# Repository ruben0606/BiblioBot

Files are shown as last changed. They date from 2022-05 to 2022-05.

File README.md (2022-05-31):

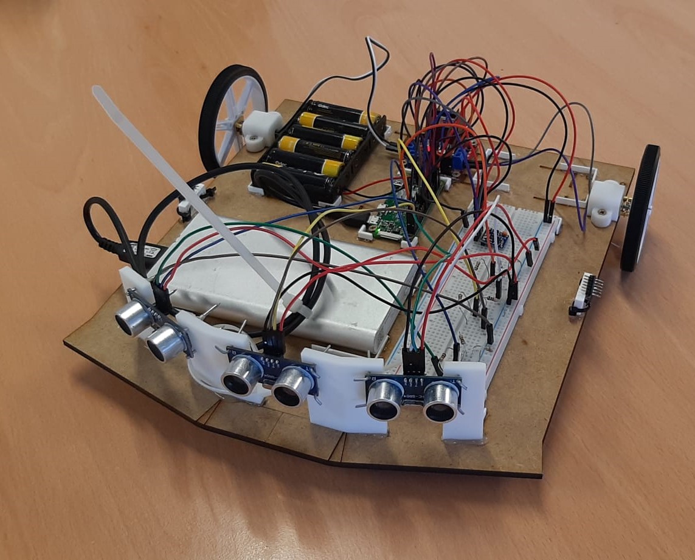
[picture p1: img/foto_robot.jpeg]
header pic


# BiblioBot
Project de l'assignatura Robòtica, llenguatge i planificació.

# Table of Contents
   * [What is this?](#what-is-this)
   * [Requirements](#requirements)
   * [Hardware](#hardware)
     * [Components](#components)
     * [Circuit](#circuit)  
     * [Resultat final](#resultat-final)
   * [Software](#software)
   * [3D printing](#3d-printing)
   * [How to use](#how-to-use)
   * [License](#license)
   * [Contribution](#contribution)
   * [Citing](#citing)
   * [Sponsors](#sponsors)
   * [Authors](#authors)
   * [Bibliography](#bibliography)

# What is this?
Projecte creat per un grup de 3 estudiants de la UAB que consisteix en la creació d'un robot dissenyat per ajudar als bibliotecaris i bibliotecàries a fer baixar el to de veu a la gent.

Features:
1. Autonomous movement module
2. Obstacle detection module
3. Audio advise module
4. Sound triangulation module
5. Person detection module

# Requirements
Per executar el codi d'aquest project:
- [Python 3.10.x](https://www.python.org/)
- [playsound](https://pypi.org/project/playsound/)
- [smbus](https://pypi.org/project/smbus-cffi/)
- [pygame](https://pypi.org/project/pygame/)
- [math](https://docs.python.org/es/3/library/math.html)
- [time](https://pypi.org/project/python-time/)

# Hardware

## Components

Per realitzar el Bibliobot s'han utilitzat una sèrie de components que podeu trobar en la seva totatilat fent click al següent enllaç:

[Enllaç components](https://github.com/ruben0606/BiblioBot/blob/main/components/components.txt)

A continucació mostrem els principals components acompanyats d'una petita explicació del seu ús en el nostre projecte.

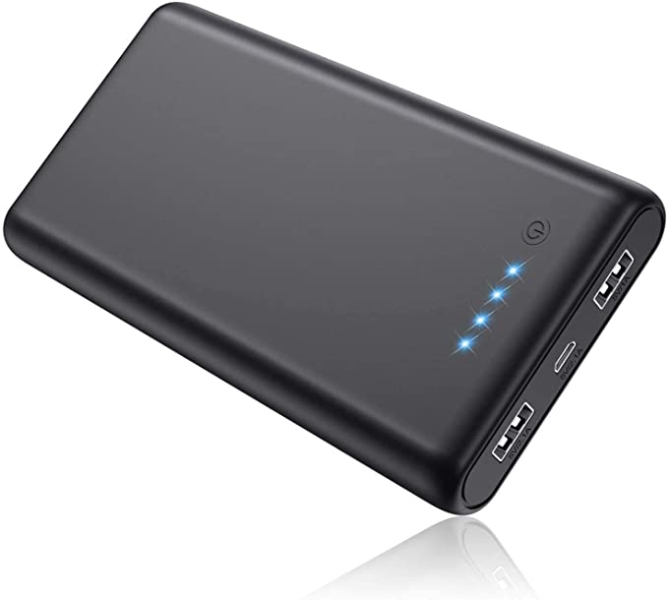
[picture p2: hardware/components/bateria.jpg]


*Batería que alimentarà els motors*

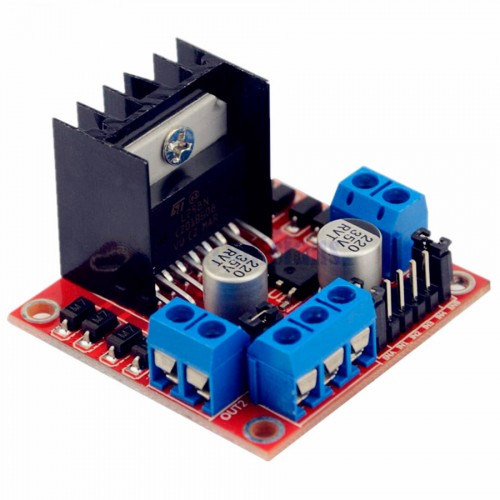
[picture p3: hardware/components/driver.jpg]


*Driver L298N que serviràn per manipulars els motors desde la Raspberry*

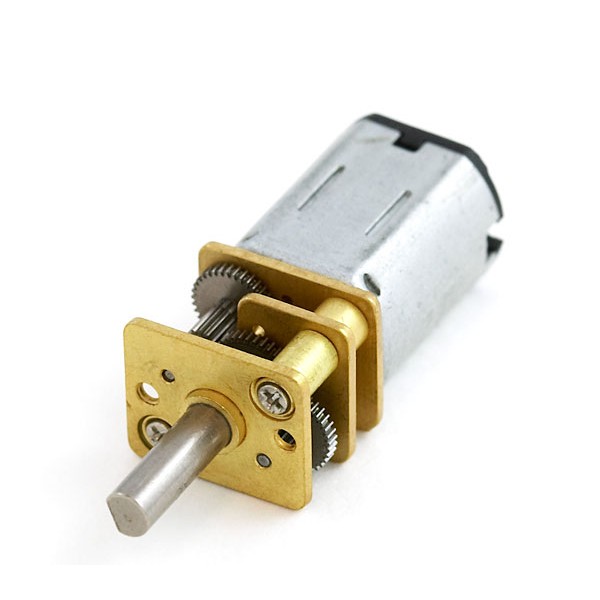
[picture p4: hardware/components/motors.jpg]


*Motors s'encarregaràn de transmetre moviment a les rodes*

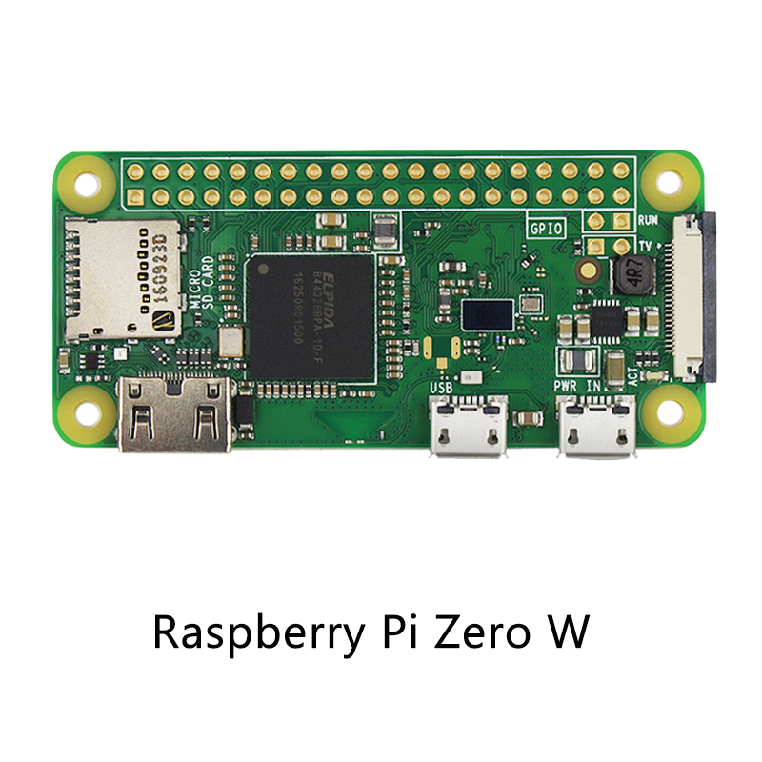
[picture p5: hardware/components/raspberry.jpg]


*Raspberry Pi Zero W, s'encarrega de controlar la resta de components*

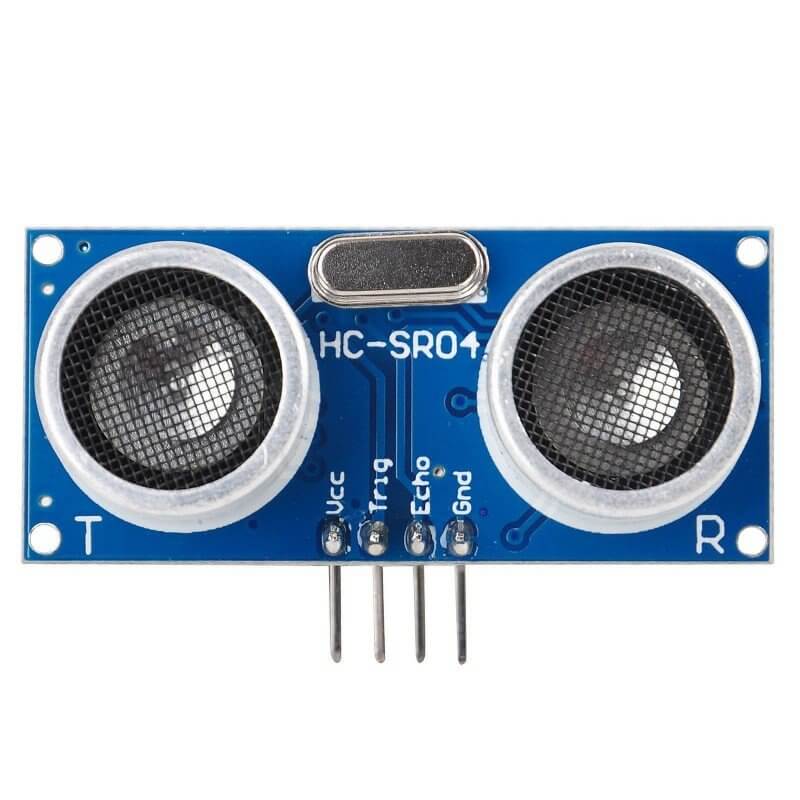
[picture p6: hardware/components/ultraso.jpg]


*Sensors d'ultrasò HC-SR04 detecta obstacles a una certa distància del robot*

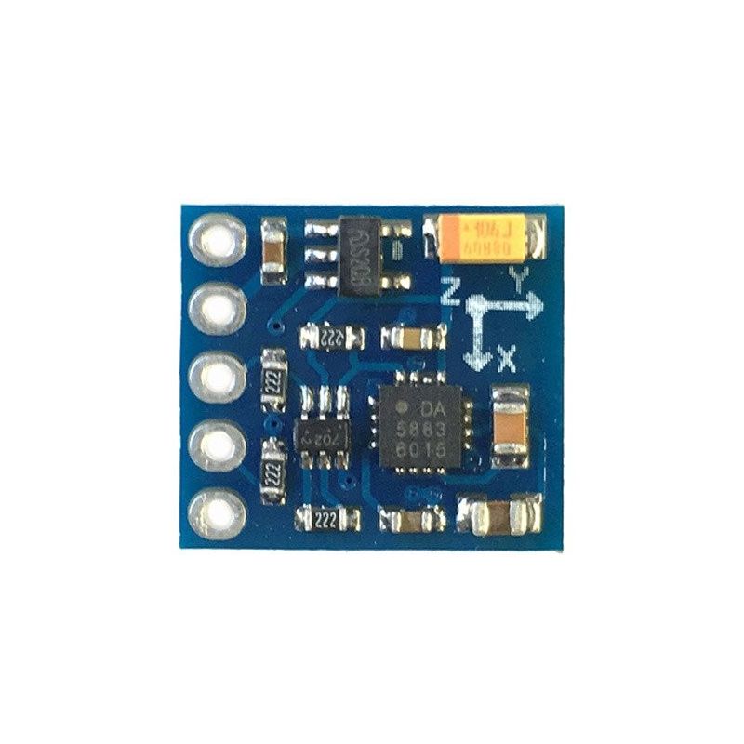
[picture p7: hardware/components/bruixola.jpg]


*Brúixola que indicarà la direcció del nord per poder orientar al Bibliobot.*

## Circuit

A continuació es pot observar una simulació del circuit necessàri realitzat amb Fritzering. Per obtenir tots els components s'haurà de descarregar una sèrie de llibreries que deixem a l'enllaç de continuació:

[Llibreries fritzering](https://github.com/adafruit/Fritzing-Library)

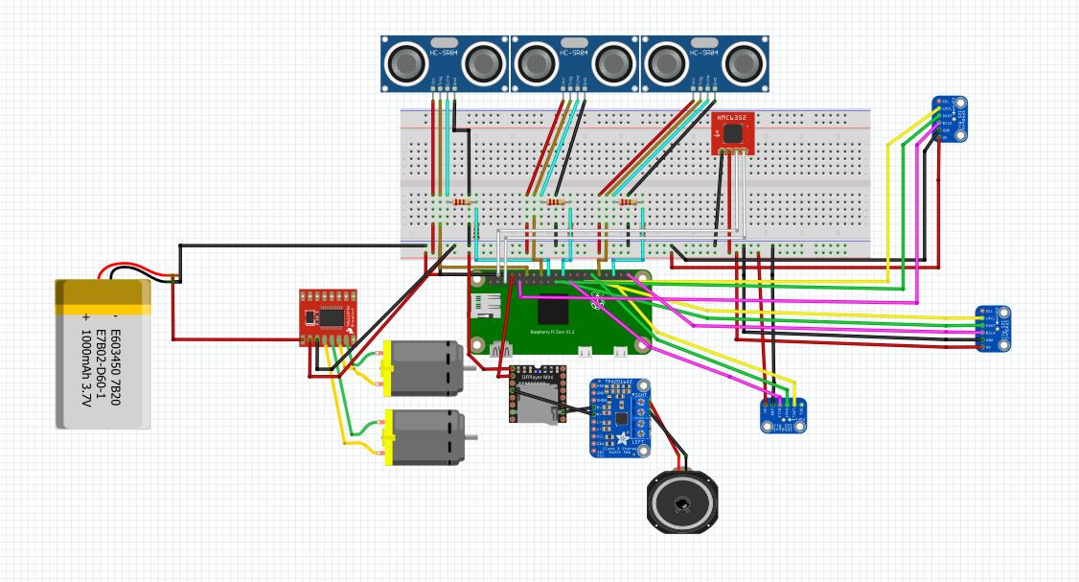
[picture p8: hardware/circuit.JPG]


Si voleu saber quins pins hem utilitzat específicament per realitzar la versió final del bibliobot els podeu consultar al següent enllaç:

[Pinout Bibliobot](/pinout_bibliobot.txt)

## Resultat final

A continuació mostrem una sèrie d'imatges de la versió final del robot.



*Imatge de la versió final del Bibliobot*

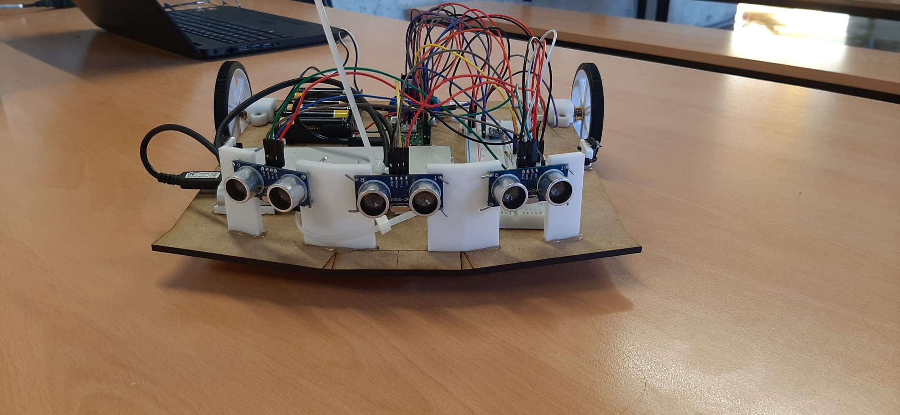
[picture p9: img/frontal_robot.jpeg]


*Vista frontal del Bibliobot*

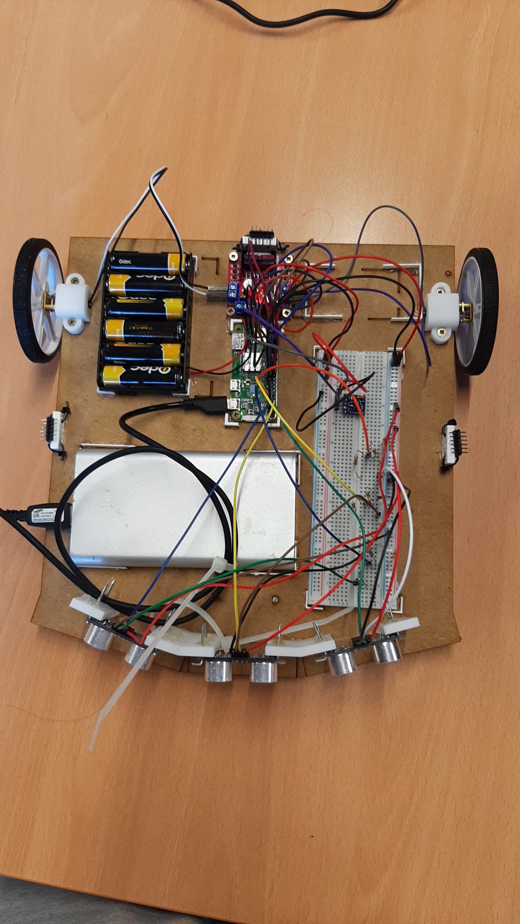
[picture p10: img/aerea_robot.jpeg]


*Vista aèrea del Bibliobot*

# Software

A nivell de software el projecte conté tres grans mòduls:

-**Mòdul de Moviment:**
S'encarrega del moviment del robot, que es podrà moure en les tres direccions programades, cap endavant, esquerra i dreta.
Simplement conté la programació perquè el robot pugui avançar cap a la direcció que se l'indiqui en tot moment segons la situació actual que tingui.
Aquesta situació actual dependrà de si el mòdul de detecció d'obstacles li informa que hem topat amb un obstacle.

-**Mòdul de detecció d'obstacles:**
S'encarrega de detectar els obstacles que el Bibliobot va trobant al llarg del seu recorregut. Aquest mòdul informarà al mòdul de moviment quan detecti un obstacle i li dirà per quina direcció l'ha detectat. Això ho sabrà segons quin sensor d'ultrasò HC-sr04 hagi detectat l'obstacle i li passarà a l'altre mòdul una senyal perquè pugui actuar.
Els sensors estàn separats amb una angle de 15 graus entre si per poder localitzar correctament si un objecte es troba davant, a l'esquerra o a la dreta i que no pugui haver confusió.

-**Mòdul de reproducció de so:**
S'encarrega de reproduïr una frase a través d'un altaveu un cop hagi arribat al destí per fer saber a la persona indicada que ha de baixar el to de veu. Depèn del mòdul de moviment per saber quan arribem al destí, que serà quan ha d'executar l'ordre.
Un cop intervé aquest mòdul Bibliobot ha acabat la seva tasca i espera a tornar a haver d'intervenir.

A continuació es mostra una imatge amb els mòduls software i les dependències entre ells:

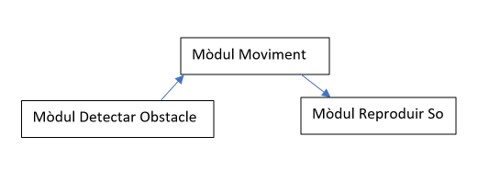
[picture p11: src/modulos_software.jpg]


**PROGRAMA PRINCIPAL**
El programa principal (main) s'encarrega d'inicialitzar els pins i variables i cridar a les funcions corresponents als mòduls de software per obtenir la solució. 
En aquest cas la crida a alguns mòduls retornarà l'entrada a uns altres (com la detecció d'obstacles i el moviment) i gestionarà a quina posició ha d'anar Bibliobot i quan ha arribat a la mateixa.
El programa consta bàsicament d'un bucle continu en el qual el robot farà el següent:

1. Prenem la direcció del robot amb la brúixola.
2. Mirem si hi han obstacles i en que posició es troben.
3. Esquivem els objectes segons on es trobin i la direcció del robot.

Del punt 3 es passarà a l'1 si no arribem a destí. En cas d'arribar el robot manarà a callar a la persona objectiu.

# 3D printing

Per a la realització del Bibliobot s'han hagut d'imprimir diverses peces 3d. Aquestes peces 3d s'han imprès a l'Open Lab de la Universitat Autònoma de Barcelona (UAB).

S'ha utilitzat el programa Fusion 360 per realitzar totes les peces.

La primera peça realitada és la peça principal del projecte ja que serà la base del nostre robot. La peça consta de la base i al seu interior hem dissenyat unes sub-peces per poder colocar els components corresponents sense que caiguin de la base amb el moviment del robot.
Aquestes subpeces són pestanyes que envolten les peces per així fixar-les a la base i al disseny es poden observar les peces que serveixen per anclar uns altres components amb cargols.

La base es va decidir fer amb la talladora làser en fusta ja que era molt més ràpid. 

A continuació mostrem el resultat:
  
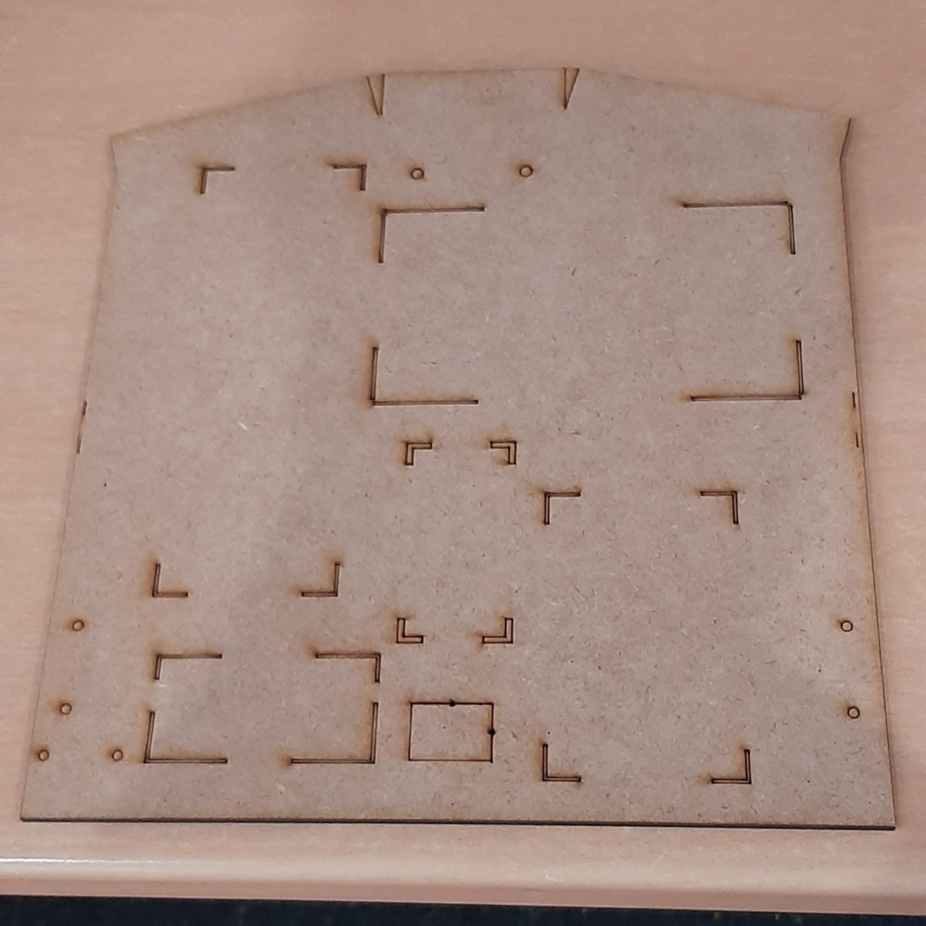
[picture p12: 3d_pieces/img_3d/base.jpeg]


*Base de fusta tallada a làser*

També es van realitzar els suports per mantenir fixos els sensors d'ultrasò HC-sr04, els motors i els micròfons. En el cas del sensors es van situar amb una diferència de 15 graus entre ells per poder detectar millor els obstàcles.

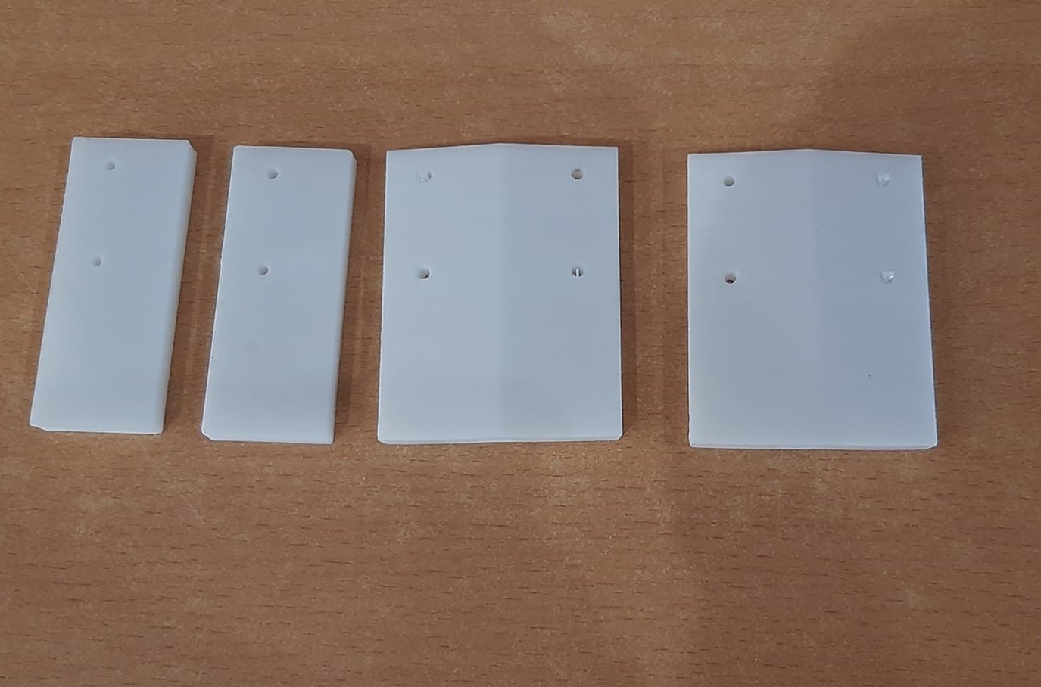
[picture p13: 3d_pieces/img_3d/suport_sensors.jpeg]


*Peces per aguantar els sensors HC-sr04 i mantenirlos a un angle de 15 graus entre ells.*

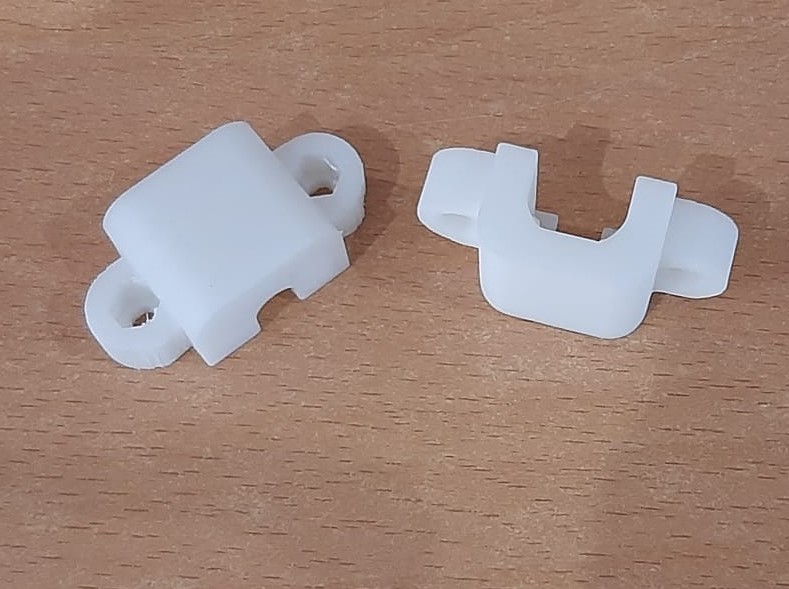
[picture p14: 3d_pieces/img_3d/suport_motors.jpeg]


*Suports de motors obtinguts d'internet*

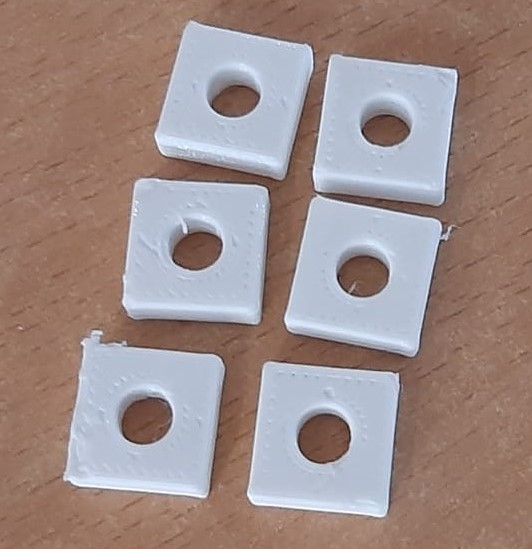
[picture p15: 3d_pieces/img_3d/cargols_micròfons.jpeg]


*Peces per aguantar els micròfons de forma que quedin triangulats*

Per últim, com hem esmentat abans, s'han realitzat múltiples pestanyes per fixar els components més pesats i amb major risc de voltejar o caure.

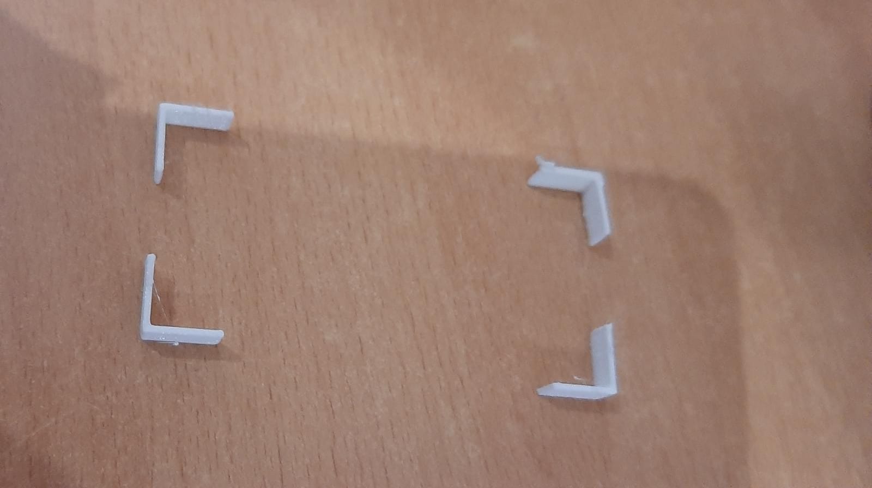
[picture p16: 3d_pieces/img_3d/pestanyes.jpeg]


*Exemple de pestanyes per fixar els components*

# How to use
1. Connectar-se el dispositiu raspberry pi zero w mitjançant ssh.

2. Clonar aquest repositori des de terminal.
> git clone https://github.com/ruben0606/BiblioBot.git

3. Instal·lar les llibreries necessaries.

Utilitzar l'eina pip:

> pip install -r requirements/requirements.txt

4. Executar el python script que es troba en la carpeta src.
> python src/Bibliobot.py

# License
MIT

# Use-case
Encara no tenim cap cas d'ús d'altres usuaris.

# Contribution
Qualsevol tipus de contribució serà benvinguda!

# Citing
Si utilitzeu el codi d'aquest projecte per al vostre propi projecte, us animem a citar els nostres treballs.

# Supporting this project
Agraïm que esteu interessats en aquest project, però no acceptem cap tipus donació.

# Sponsors

### [Open Labs UAB](https://www.uab.cat/open-labs/)

Impressió de peces 3D amb ells de forma gratuïta per projecte de la UAB.

### [Universitat Atònomma de Barcelona (UAB)](https://www.uab.cat/)

Facilitació dels components necessàris per la realització del projecte.

# Authors
- [Col·laboradors d'aquest project](https://github.com/ruben0606/BiblioBot/graphs/contributors)

# Bibliography
1. https://rlpengineeringschooluab2017.wordpress.com/2017/05/31/soundhound/
2. https://rlpengineeringschooluab2017.wordpress.com/2017/05/30/the-follower/
3. https://www.electronicshub.org/raspberry-pi-l298n-interface-tutorial-control-dc-motor-l298n-raspberry-pi/
4. https://cdn.sparkfun.com/assets/learn_tutorials/6/7/6/PiZero_1.pdf
5. https://blog.330ohms.com/2020/06/17/como-conectar-un-sensor-ultrasonico-a-raspberry-pi/
6. https://github.com/ShrimpingIt/micropython-dfplayer
7. https://www.reddit.com/r/raspberrypipico/comments/q19v0n/dfplayer_with_pico/
8. https://www.electroallweb.com/index.php/2020/07/22/modulo-dfplayer-mini-reproductor-mp3-tutorial-completo/
9. https://pimylifeup.com/raspberry-pi-omxplayer/
10. https://www.hackster.io/miguel-a-lopez-monzon/triangulation-of-sound-87d3b8
11. https://forums.raspberrypi.com/viewtopic.php?t=165996
12. https://forum.arduino.cc/t/sound-triangulation-with-3-microphones/122940
13. https://www.youtube.com/watch?v=3LBiyBTnt7g&ab_channel=Maker%27sDigest
14. http://dimcad3d.com/2016/04/27/fusion-360-tutoriales-en-espanol/
15. https://descubrearduino.com/audio-bluetooth-raspberry-pi/
16. https://www.electronicwings.com/raspberry-pi/mpu6050-accelerometergyroscope-interfacing-with-raspberry-pi
17. https://forums.raspberrypi.com/viewtopic.php?t=184556
18. https://electropeak.com/learn/interfacing-gy-271-hmc5883l-compass-magnetometr-with-arduino/
19. https://arduinoque.com/robots/sensor-de-movimiento-raspberry-pi/
20. https://forums.raspberrypi.com/viewtopic.php?t=166156
21. https://components101.com/modules/l293n-motor-driver-module

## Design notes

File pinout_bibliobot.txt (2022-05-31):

BOARD PINS

HC-RS04
----------
TRIGL = 40
TRIGC = 38
TRIGR = 36

ECHOL = 37
ECHOC = 35
ECHOR = 33

GY-271
----------
SCL = 3
SDA = 5

L298N
----------
IN1 = 16
IN2 = 18
IN3 = 19
IN4 = 15
ENA = 22
ENB = 23

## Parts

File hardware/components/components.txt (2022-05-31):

-Raspberry pi zero w
-Sensors dl'ultrasò HC-SR04 (x3)
-Protoboard
-Drivers L298N
-Altaveu bluetooth
-Motor Micrometal LP
-Batería Lipo
-Rodes(x2)
-Roda boja
-Portapiles (6 piles)
-Micròfons I2S SPH0645

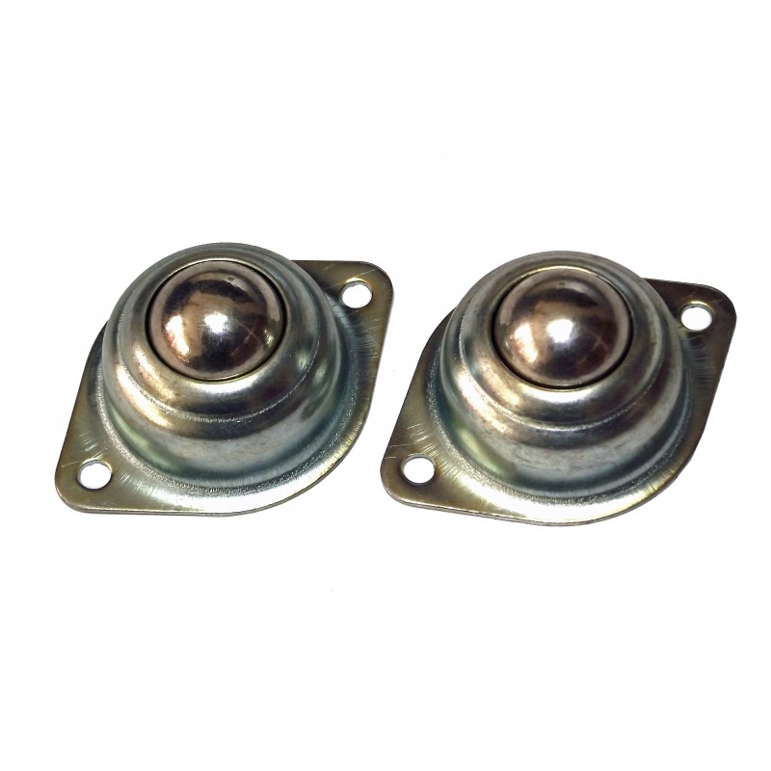
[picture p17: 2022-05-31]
hardware/components/roda_boja.jpg

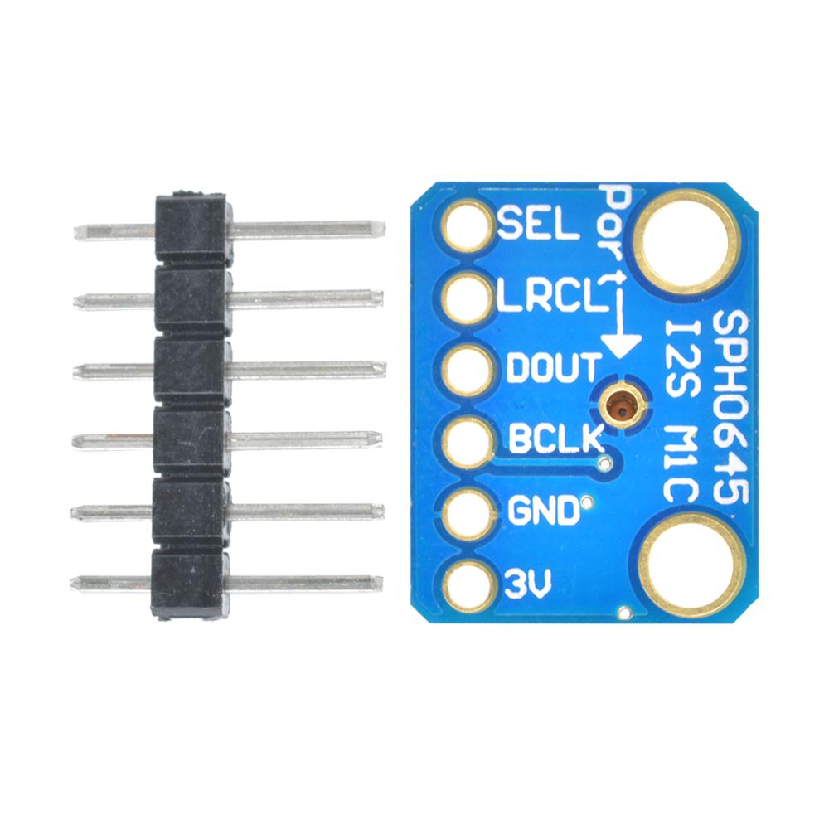
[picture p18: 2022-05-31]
hardware/components/microfons.jpeg

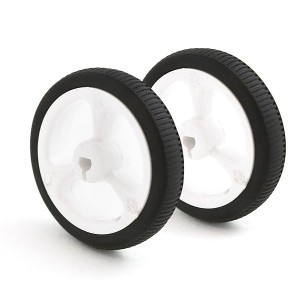
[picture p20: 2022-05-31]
hardware/components/rodes.jpg

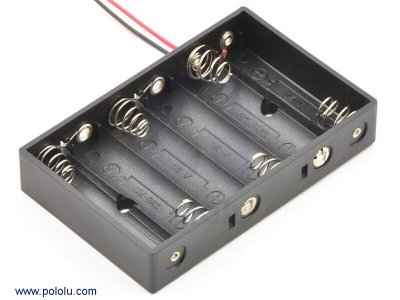
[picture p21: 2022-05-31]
hardware/components/portapiles.jpg

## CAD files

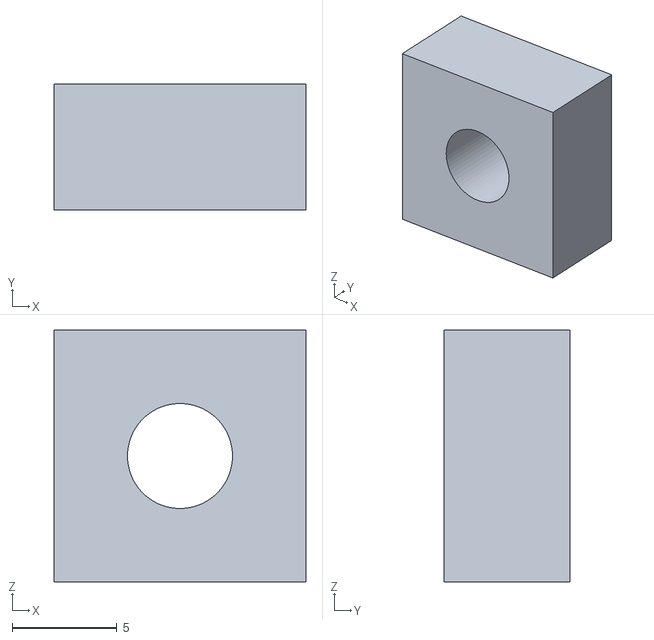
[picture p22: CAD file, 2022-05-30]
3d_pieces/soporte_micros.stl
12.0 x 6.00 x 12.0

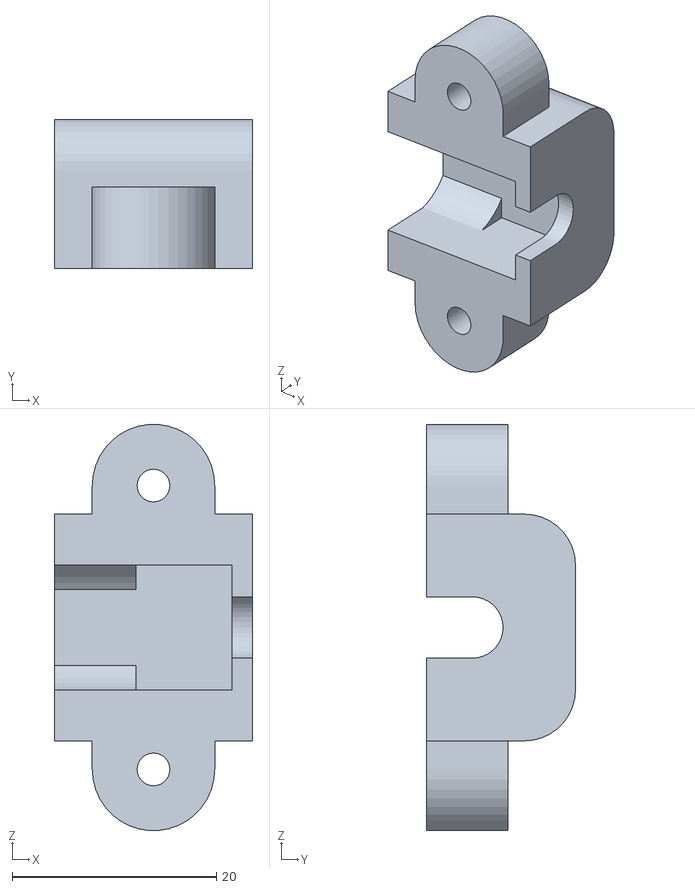
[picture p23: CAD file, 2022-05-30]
3d_pieces/soporte_motores.STL
19.4 x 14.6 x 39.8

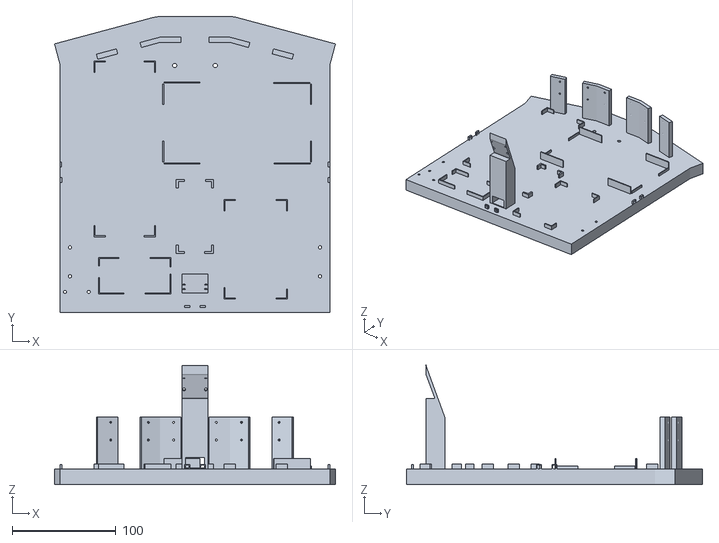
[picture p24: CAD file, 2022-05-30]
3d_pieces/base_robot.stl
270.3 x 285.0 x 114.9

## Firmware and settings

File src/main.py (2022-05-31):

import RPi.GPIO as GPIO
import time
import smbus  # comunicación I2C
import math
import pygame


# direcciones requeridas
# ---------------config
Registro_A = 0x0B
Registro_B = 0x09
RegStatus = 0x06
RegCtrl = 0x09
# ---------------direcciones de la conexión
bus = smbus.SMBus(1)
deviceAdress = 0x0d
# ---------------datos
eje_X_Mag = 0x00
eje_Y_Mag = 0x02
eje_Z_Mag = 0x04
declination = -0.00669
pi = 3.14159265359


distance_thfreshold = 15

#PINOUT
#HC-RS04
#----------
TRIGL = 40
TRIGC = 38
TRIGR = 36

ECHOL = 37
ECHOC = 35
ECHOR = 33

#GY-271
#----------
SCL = 3
SDA = 5

#L298N
#----------
IN1 = 16
IN2 = 18
IN3 = 19
IN4 = 15
ENA = 22
ENB = 23

TIME = 20

GPIO.setmode(GPIO.BOARD)

GPIO.setup(TRIGL,GPIO.OUT)
GPIO.setup(TRIGC,GPIO.OUT)
GPIO.setup(TRIGR,GPIO.OUT)
GPIO.setup(IN1,GPIO.OUT)
GPIO.setup(IN2,GPIO.OUT)
GPIO.setup(IN3,GPIO.OUT)
GPIO.setup(IN4,GPIO.OUT)
GPIO.setup(ENA,GPIO.OUT)
GPIO.setup(ENB,GPIO.OUT)

GPIO.setup(ECHOL,GPIO.IN)
GPIO.setup(ECHOC,GPIO.IN)
GPIO.setup(ECHOR,GPIO.IN)

def ultrasound(TRIG, ECHO):
    # print("Distance in cm: ")

    try:
        GPIO.output(TRIG, False)
        print("Waiting to settle sensor")
        time.sleep(0.5)
        GPIO.output(TRIG, True)
        time.sleep(0.00001)
        GPIO.output(TRIG, False)
        while True:
            pulse_start = time.time()
            if GPIO.input(ECHO) == GPIO.HIGH:
                break
        while True:
            pulse_end = time.time()
            if GPIO.input(ECHO) == GPIO.LOW:
                break
        pulse_duration = pulse_end - pulse_start
        distance = pulse_duration * 17150
        distance = round(distance, 2)
        print("Distance: %f cm", distance)
        return distance

    except KeyboardInterrupt:
        print("Interrupted")
        GPIO.cleanup()


def movement(dir_obj, dir_robot, obstacles): #obstacles = [right, center, left] (bools) if obstacle or not
    if dir_obj == dir_robot:
        if obstacles[1] == True:
            #go forward
            GPIO.output(IN1, GPIO.LOW)
            GPIO.output(IN2, GPIO.HIGH)
            GPIO.output(IN3, GPIO.LOW)
            GPIO.output(IN4, GPIO.HIGH)
        elif obstacles[2] == True:
            #turn right
            GPIO.output(IN1, GPIO.HIGH)
            GPIO.output(IN2, GPIO.LOW)
            GPIO.output(IN3, GPIO.LOW)
            GPIO.output(IN4, GPIO.HIGH)
        elif obstacles[0] == True:
            #turn left
            GPIO.output(IN1, GPIO.LOW)
            GPIO.output(IN2, GPIO.HIGH)
            GPIO.output(IN3, GPIO.HIGH)
            GPIO.output(IN4, GPIO.LOW)
        else:
            #detenerse
            GPIO.output(IN1, GPIO.LOW)
            GPIO.output(IN2, GPIO.LOW)
            GPIO.output(IN3, GPIO.LOW)
            GPIO.output(IN4, GPIO.LOW)
    else:
        #alinear direccion
        if dir_robot - dir_obj < 0:
            #turn right
            GPIO.output(IN1, GPIO.HIGH)
            GPIO.output(IN2, GPIO.LOW)
            GPIO.output(IN3, GPIO.LOW)
            GPIO.output(IN4, GPIO.HIGH)
        elif dir_robot - dir_obj > 0:
            # turn left
            GPIO.output(IN1, GPIO.LOW)
            GPIO.output(IN2, GPIO.HIGH)
            GPIO.output(IN3, GPIO.HIGH)
            GPIO.output(IN4, GPIO.LOW)

def MagnetometerInit():
    # configurar registro A
    bus.write_byte_data(deviceAdress, Registro_A, 0x01)
    # configurar registro B
    bus.write_byte_data(deviceAdress, Registro_B, 0x1D)
    # configurar registro para seleccionar el modo
    # bus.write_byte_data(deviceAdress, ModoRegistro, 0)

def read_raw_data(addr):
    # leer doble byte (16 bits)
    low = bus.read_byte_data(deviceAdress, addr)
    high = bus.read_byte_data(deviceAdress, addr + 1)
    # concatenar los bytes
    valor = ((high << 8) | low)
    # obtener el signo
    if (valor > 32768):
        valor = valor - 65536
    return valor

def accelerometro():
    print('leyendo magnetometro...')
    #while True:
    bandera = bus.read_byte_data(deviceAdress, RegStatus)
    a = "{0:b}".format(bandera)
    if a[len(a) - 1] == 0:
        bandera = bus.read_byte_data(deviceAdress, RegStatus)
    x = read_raw_data(eje_X_Mag)
    y = read_raw_data(eje_Y_Mag)
    z = read_raw_data(eje_Z_Mag)
    heading = math.atan2(y, x) + declination
    # compensar superiores a 360
    if (heading > 2 * pi):
        heading = heading - 2 * pi
    # revisar el signo
    if (heading < 0):
        heading = heading + 2 * pi
        # convertir a grados
    heading_angle = int(heading * (180 / pi))
    print("angulo = %d°" % heading_angle)
    #sleep(0.5)
    return heading_angle

def call():
    pygame.mixer.init()
    pygame.mixer.music.load("king.mp3")
    pygame.mixer.music.play()
    while pygame.mixer.music.get_busy() == True:
        continue

def main():
    start = time.time()
    MagnetometerInit()
    dir_objetivo = 100
    while True:
        dir_robot = accelerometro()
        distances = []
        dist_1 = ultrasound(TRIGR, ECHOR)
        distances.append(dist_1)
        dist_2 = ultrasound(TRIGC, ECHOC)
        distances.append(dist_2)
        dist_3 = ultrasound(TRIGL, ECHOL)
        distances.append(dist_3)
        obstacles = []
        for dist in distances:
            if dist < distance_thfreshold:  # si la distancia en un detector es menor a la minima
                obstacles.append(True)
            else:
                obstacles.append(False)
        movement(dir_objetivo,dir_robot,obstacles)
        end = time.time()
        if end - start > TIME:
            break
    call()

if __name__ == '__main__':
    main()

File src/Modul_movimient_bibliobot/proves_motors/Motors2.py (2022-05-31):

# -*- coding: utf-8 -*-
"""
Created on Wed May 25 09:44:07 2022

@author: rubeg
"""
#PROVA 2 MOTORS

import RPi.GPIO as GPIO
from time import sleep
 
GPIO.setmode(GPIO.BOARD)
Motor1A = 16
Motor1B = 18
Motor1E = 22
Motor2A = 23
Motor2B = 21
Motor2E = 19
GPIO.setup(Motor1A,GPIO.OUT)
GPIO.setup(Motor1B,GPIO.OUT)
GPIO.setup(Motor1E,GPIO.OUT)

GPIO.setup(Motor2A,GPIO.OUT)
GPIO.setup(Motor2B,GPIO.OUT)
GPIO.setup(Motor2E,GPIO.OUT)

print("Going forwards")

GPIO.output(Motor1A,GPIO.HIGH)
GPIO.output(Motor1B,GPIO.LOW)
GPIO.output(Motor1E,GPIO.HIGH)

GPIO.output(Motor2A,GPIO.HIGH)
GPIO.output(Motor2B,GPIO.LOW)
GPIO.output(Motor2E,GPIO.HIGH)
sleep(2)

print("Going backwards")
GPIO.output(Motor1A,GPIO.LOW)
GPIO.output(Motor1B,GPIO.HIGH)
GPIO.output(Motor1E,GPIO.HIGH)
 
GPIO.output(Motor2A,GPIO.LOW)
GPIO.output(Motor2B,GPIO.HIGH)
GPIO.output(Motor2E,GPIO.HIGH)
sleep(2)

print("Now stop")

GPIO.output(Motor1E,GPIO.LOW)
GPIO.output(Motor2E,GPIO.LOW)
 
GPIO.cleanup()

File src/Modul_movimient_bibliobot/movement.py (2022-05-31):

# -*- coding: utf-8 -*-
"""
Created on Tue May 31 23:35:06 2022

@author: rubeg
"""

import curses
import RPi.GPIO as GPIO

GPIO.setmode(GPIO.BCM)
GPIO.setup(20, GPIO.OUT)
GPIO.setup(26, GPIO.OUT)
GPIO.setup(19, GPIO.OUT)
GPIO.setup(16, GPIO.OUT)

def main(letra):
    while True:
        curses.halfdelay(1)
        key = letra.getch()
        #print key
        if key == 113:
            break
        elif key == 119:
            print "adelante"
            GPIO.output(20, GPIO.LOW)
            GPIO.output(26, GPIO.HIGH)
            GPIO.output(19, GPIO.LOW)
            GPIO.output(16, GPIO.HIGH)
        elif key == 97:
            print "izquierda"
            GPIO.output(20, GPIO.LOW)
            GPIO.output(26, GPIO.HIGH)
            GPIO.output(19, GPIO.HIGH)
            GPIO.output(16, GPIO.LOW)
        elif key == 115:
            print "atras"
            GPIO.output(20, GPIO.HIGH)
            GPIO.output(26, GPIO.LOW)
            GPIO.output(19, GPIO.HIGH)
            GPIO.output(16, GPIO.LOW)
        elif key == 100:
            print "derecha"
            GPIO.output(20, GPIO.HIGH)
            GPIO.output(26, GPIO.LOW)
            GPIO.output(19, GPIO.LOW)
            GPIO.output(16, GPIO.HIGH)
        else:
            print "detenido"
            GPIO.output(20, GPIO.LOW)
            GPIO.output(26, GPIO.LOW)
            GPIO.output(16, GPIO.LOW)
            GPIO.output(19, GPIO.LOW)
    
curses.wrapper(main)
GPIO.cleanup()
